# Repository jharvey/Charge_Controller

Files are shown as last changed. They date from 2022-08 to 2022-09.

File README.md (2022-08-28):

# FUGU-ARDUINO-MPPT-HARDWARE-KICAD
An open source Arduino ESP32 MPPT Solar Charge Controller firmware equipped with charging algorithms, WiFi, LCD menus &amp; more!
Stay tuned for the design release and video tutorial.<br>

Orginal Firmware project found here https://github.com/AngeloCasi/FUGU-ARDUINO-MPPT-FIRMWARE<br>
Oringal Hardware project found here https://drive.google.com/drive/folders/1Sd2jWAb-F8NAXlJ6PLdhcnPDQV0alD15?usp=sharing<br>

<div align="center">
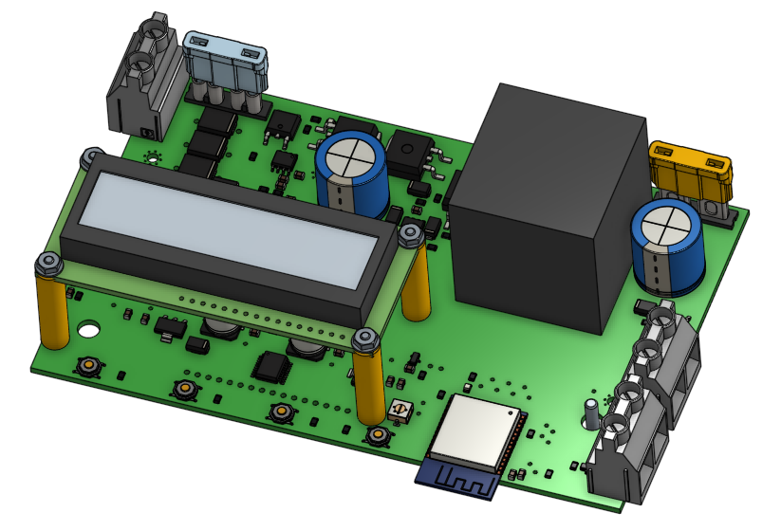
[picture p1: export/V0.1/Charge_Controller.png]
FUGU MPPT Charge Controller

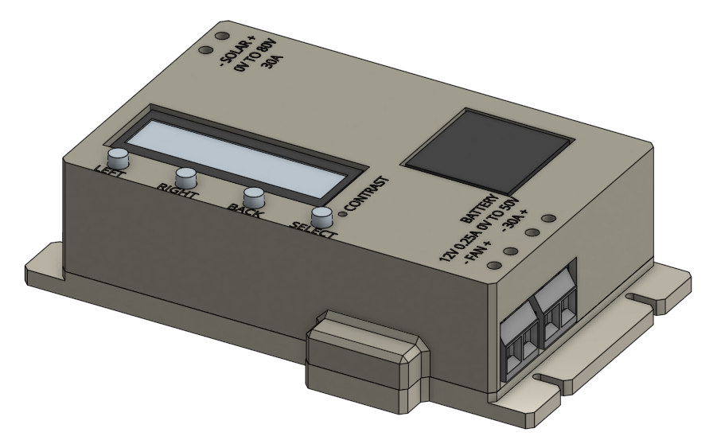
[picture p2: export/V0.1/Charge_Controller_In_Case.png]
FUGU MPPT Charge Controller

<div align="left">
OnShape 3D found here https://cad.onshape.com/documents/5882843f0ee96e62ba8b9faf/w/820f02cb3842ce32ae850702/e/1fe43df2095ddf6be5cc563b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<br>
GPL open-source DIY Charge Controller<br>

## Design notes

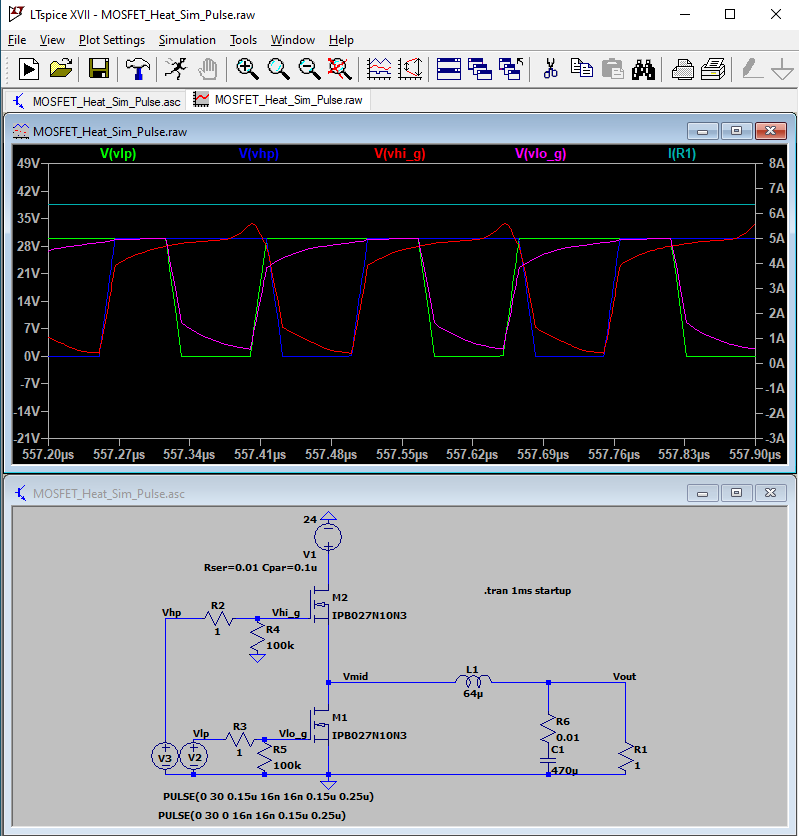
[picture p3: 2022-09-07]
Simulations/MOS_Heat_LTSpice/MOSFET_Heat_Sim_Pulse.png

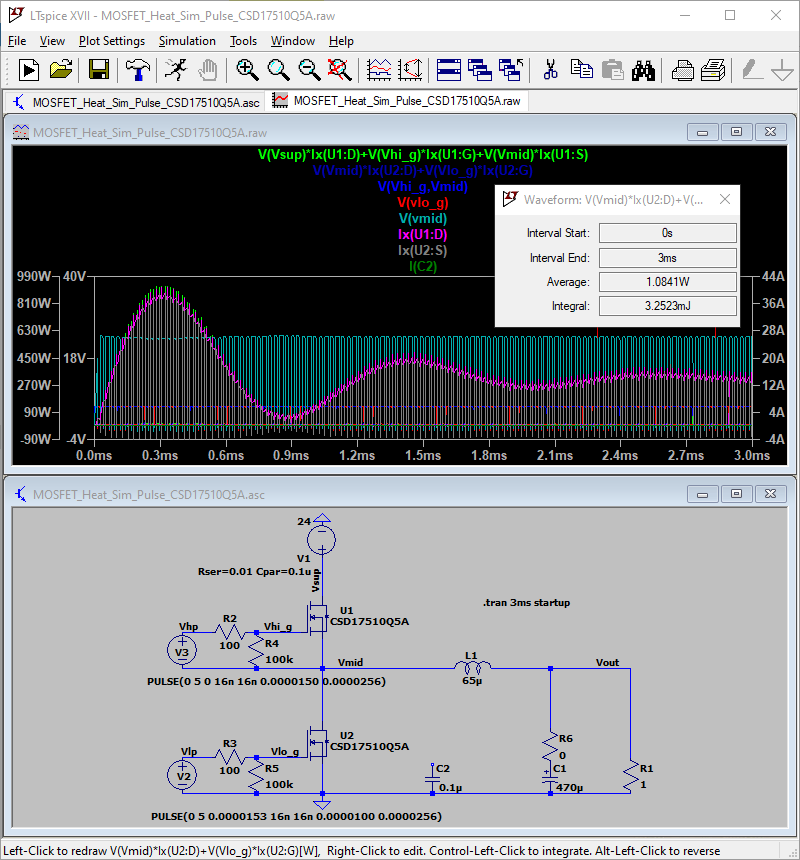
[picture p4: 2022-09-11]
Simulations/MOS_Heat_LTSpice/Low_Side_1.08W_at_12A_Out.png

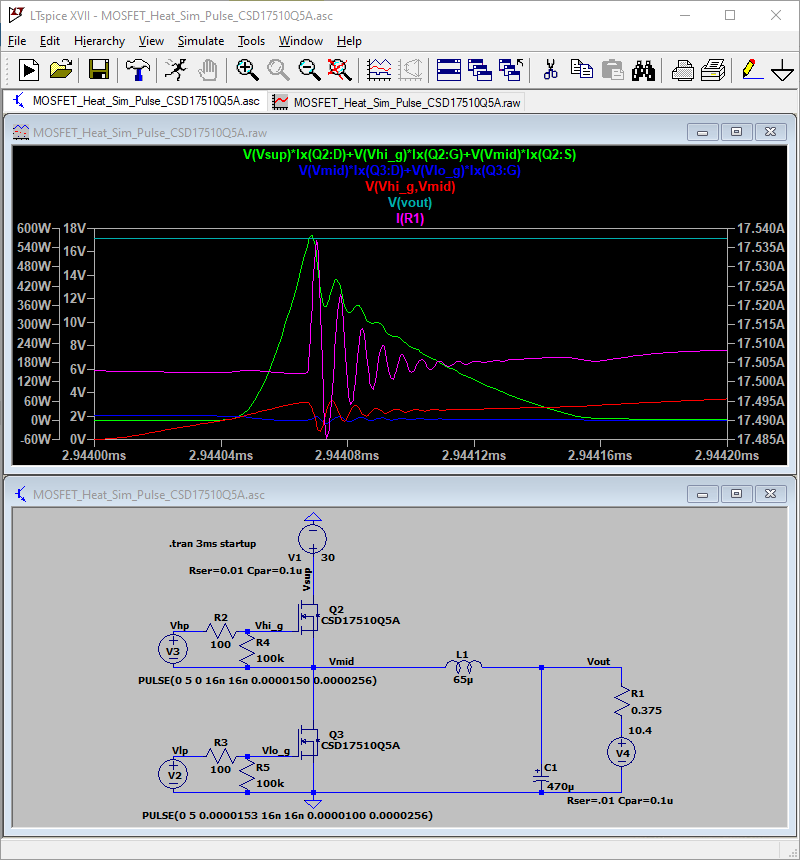
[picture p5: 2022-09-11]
Simulations/MOS_Heat_LTSpice/HeatSim_Q2_Transients_at_30Vin_with_2.944mS_600Wpeak.png

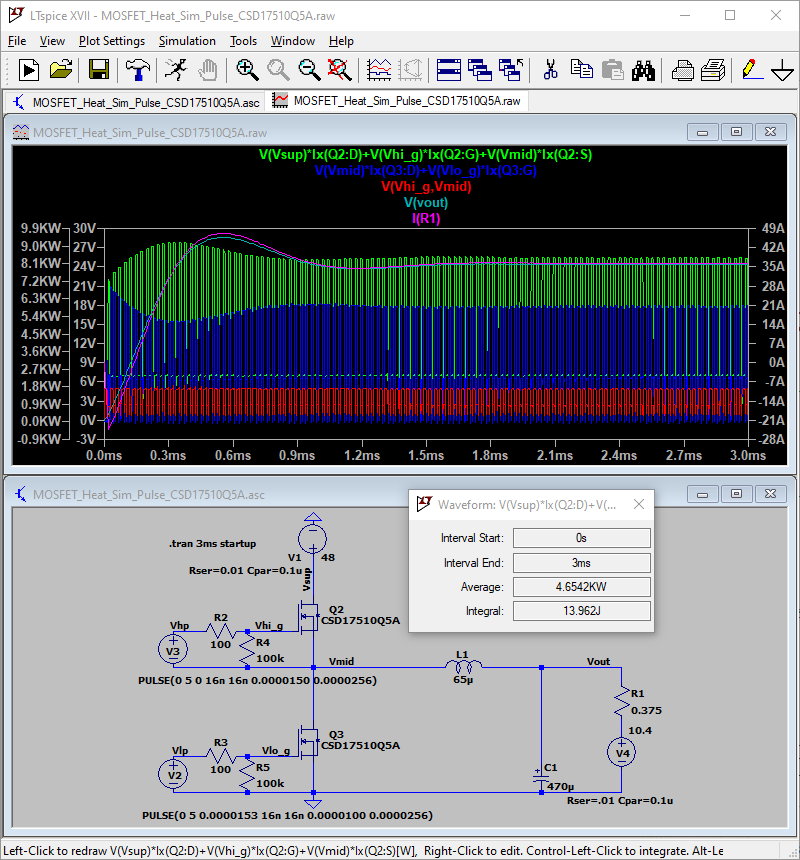
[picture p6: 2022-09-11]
Simulations/MOS_Heat_LTSpice/HeatSim_Q2_4.65kW_at_48Vin_with_36A_26V_Out_Batter_Charger.png

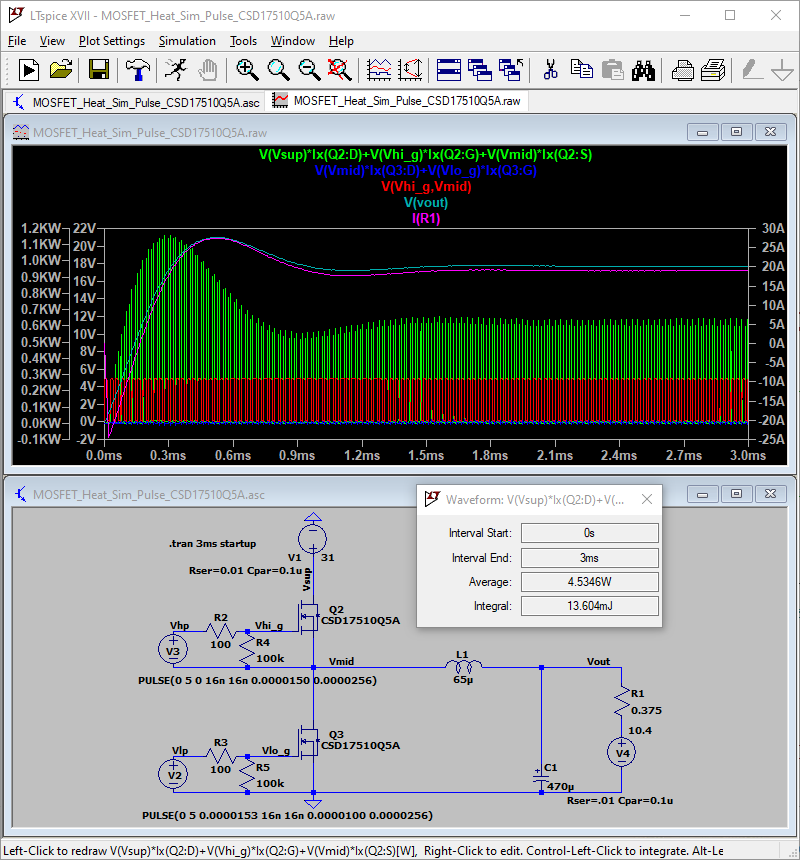
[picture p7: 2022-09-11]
Simulations/MOS_Heat_LTSpice/HeatSim_Q2_4.53W_at_31Vin_with_19A_18V_Out_Batter_Charger.png

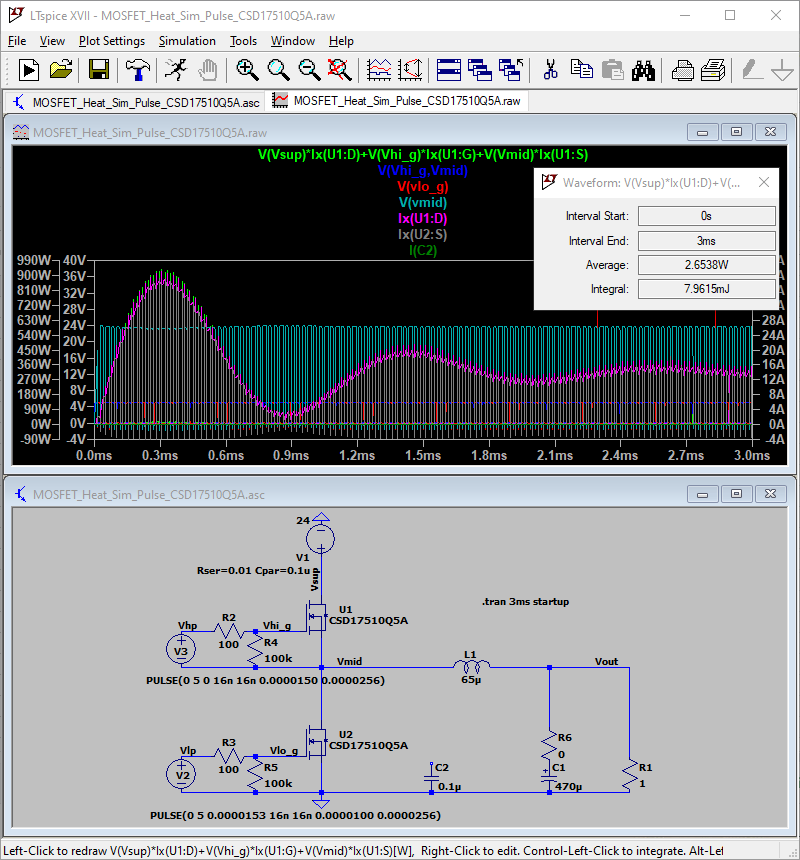
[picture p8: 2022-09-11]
Simulations/MOS_Heat_LTSpice/High_Side_2.65W_at_12A_Out.png

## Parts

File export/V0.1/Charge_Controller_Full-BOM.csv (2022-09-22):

Comment | Designator | Footprint | LCSC
100nf | C1,C3,C4,C11,C12,C13,C20,C23,C25,C26,C27 | Capacitor_SMD:C_0805_2012Metric | C28233
10uf | C10 | Capacitor_SMD:C_0805_2012Metric | C15850
100uf | C14,C16 | Capacitor_SMD:CP_Elec_8x10 | C445063
33nf | C15,C17 | Capacitor_SMD:C_0805_2012Metric | C53175
4.7uf | C18 | Capacitor_THT:CP_Radial_D10.0mm_P5.00mm | C503212
470nf | C19,C28 | Capacitor_SMD:C_0805_2012Metric | C13967
2.2uf | C2,C9 | Capacitor_SMD:C_0805_2012Metric | C49217
4.7uf | C5,C6,C21,C22,C24 | Capacitor_SMD:C_0805_2012Metric | C1779
470uf | C7,C8 | Capacitor_THT:CP_Radial_D16.0mm_P7.50mm | C513392
SS310 | D1,D2,D3,D5,D6,D7 | Diode_SMD:D_SMA | C15874
90V-34A | D11,D12,D13 | Diode_SMD:D_SMC-RM10_Universal_Handsoldering | C2912801
1N4007 | D4,D8 | Diode_SMD:D_SMA | C727081
D_Zener_Small | D9,D10 | Diode_SMD:D_MiniMELF | C8062
LCD | DS1 | LCD:LCD_LCM-S01602DTR_A | C83275
25A | F1,F2 | Symbol:ESD-Logo_6.6x6mm_SilkScreen | C116701
Holder | H1,H2 | Fuse_Holder:Fuse_Blade_C2935871 | C2935871
100x41x8mm Aluminum Heat Sink | HS1 | MountingHole:MountingHole_2.5mm_Pad_Via | NA
SOLAR | J1 | TerminalBlock_MetzConnect:TerminalBlock_MetzConnect_Type703_RT10N02HGLU_1x02_P9.52mm_Horizontal | C92145
Conn_01x01_Female | J2,J3,J4,J5,J6,J7,J10,J11,J12,J13,J14,J15,J16,J17,J18,J19,J20,J21,J22,J23,J24,J25,J26,J27,J28,J29,J30,J31,J32 | TestPoint:TestPoint_Loop_D3.50mm_Drill0.9mm_Beaded | NA
Conn_01x01_Female | J33,J34 | MountingHole:MountingHole_2.5mm_Pad_Via | NA
FAN | J36 | TerminalBlock_MetzConnect:TerminalBlock_MetzConnect_Type703_RT10N02HGLU_1x02_P9.52mm_Horizontal | C92145
I2C_CON | J38 | Connector_PinHeader_2.54mm:PinHeader_1x04_P2.54mm_Vertical | NA
BATT | J8 | TerminalBlock_MetzConnect:TerminalBlock_MetzConnect_Type703_RT10N02HGLU_1x02_P9.52mm_Horizontal | C92145
USB_OTG | J9 | Connector_USB:USB_Micro-AB_Molex_47590-0001 | C136001
64uH | L1 | Inductor_THT:L_Axial_L30.0mm_D8.0mm_P35.56mm_Horizontal_Fastron_77A | NA
7443783533650 | L11 | 7443783533650_inductor:7443783533650 | NA
100uH | L2,L3 | Inductor_SMD:L_Taiyo-Yuden_NR-60xx_HandSoldering | C88132
LED | LED1,LED2 | LED_SMD:LED_0805_2012Metric | C84256
Logo_Open_Hardware_Small | LOGO1 | Symbol:OSHW-Symbol_6.7x6mm_SilkScreen | NA
CSD19505 | Q1,Q2,Q3 | Package_TO_SOT_SMD:TO-263-2 | C485534
Si2306 | Q4,Q9 | Package_TO_SOT_SMD:SOT-23 | C347489
2N3904 | Q5,Q6 | Package_TO_SOT_SMD:SOT-23 | C18536
PMOS-100V-78A | Q7,Q8 | Package_TO_SOT_SMD:TO-252-2 | C216784
200k | R1 | Resistor_SMD:R_0805_2012Metric | C17539
15k | R14,R15,R17,R18 | Resistor_SMD:R_0805_2012Metric | C17475
5.1k | R2 | Resistor_SMD:R_0805_2012Metric | C27834
3.3k | R3 | Resistor_SMD:R_0805_2012Metric | C26010
47k | R32,R33 | Resistor_SMD:R_0805_2012Metric | C17713
10k_-tc | R35 | Connector_PinHeader_2.54mm:PinHeader_1x02_P2.54mm_Vertical | NA
0R | R38,R39 | Resistor_SMD:R_0603_1608Metric | C21189
10k | R4,R6,R7,R12,R13,R20,R21,R22,R23,R24,R25,R26,R27,R28,R29,R30,R31,R36,R37,R43,R46,R47,R48 | Resistor_SMD:R_0805_2012Metric | C17724
330 | R49 | Resistor_SMD:R_0805_2012Metric | C17630
1k | R5,R16,R19,R34,R41,R42 | Resistor_SMD:R_0805_2012Metric | C17513
100k | R8,R11,R40 | Resistor_SMD:R_0805_2012Metric | C149504
100 | R9,R10 | Resistor_SMD:R_0805_2012Metric | C17408
10k | RV1 | Potentiometer_SMD:Potentiometer_Bourns_3314G_Vertical | C780220
RIGHT | SW1 | Button_Switch_SMD:SW_SPST_EVQQ2 | C318884
LEFT | SW2 | Button_Switch_SMD:SW_SPST_EVQQ2 | C318884
BACK | SW3 | Button_Switch_SMD:SW_SPST_EVQQ2 | C318884
SELECT | SW4 | Button_Switch_SMD:SW_SPST_EVQQ2 | C318884
Hall Amp Sense | U1 | Package_SO:SOIC-8_3.9x4.9mm_P1.27mm | C2930869
ADS1015 | U10 | Package_SO:TSSOP-10_3x3mm_P0.5mm | C193969
NUP4202 | U11 | Package_TO_SOT_SMD:SOT-363_SC-70-6 | C89319
PCF8574 | U12 | Package_SO:SSOP-20_5.3x7.2mm_P0.65mm | C57790
B1212 | U2 | Converter_DCDC:Converter_DCDC_muRata_CRE1xxxxxxSC_THT | C5127060
AMS1117-5.0 | U3 | Package_TO_SOT_SMD:SOT-223-3_TabPin2 | C6187
AMS1117-3.3 | U4 | Package_TO_SOT_SMD:SOT-223-3_TabPin2 | C6186
XL7005A | U5,U6 | Package_SO:SOIC-8_3.9x4.9mm_P1.27mm | C50848
IR2104 | U7 | Package_SO:SOIC-8_3.9x4.9mm_P1.27mm | C2960
ESP32-WROOM-32 | U8 | RF_Module:ESP32-WROOM-32 | C701343
CH340C | U9 | Package_SO:STC_SOP-16_3.9x9.9mm_P1.27mm | C84681
Comment | na | na | McMaster
Passivated 18-8 Stainless Steel Phillips Flat Head Screw 82 Degree Countersink 2-56 Thread 1-1/2" Long |  |  | 91771A267
Passivated 18-8 Stainless Steel Phillips Flat Head Screw 82 Degree Countersink 2-56 Thread 1-1/2" Long |  |  | 91771A267
Passivated 18-8 Stainless Steel Phillips Flat Head Screw 82 Degree Countersink 2-56 Thread 1-1/2" Long |  |  | 91771A267
Passivated 18-8 Stainless Steel Phillips Flat Head Screw 82 Degree Countersink 2-56 Thread 1-1/2" Long |  |  | 91771A267
316 Stainless Steel Washer for Number 2 Screw Size 0.094" ID 0.25" OD |  |  | 90107A003
316 Stainless Steel Washer for Number 2 Screw Size 0.094" ID 0.25" OD |  |  | 90107A003
316 Stainless Steel Washer for Number 2 Screw Size 0.094" ID 0.25" OD |  |  | 90107A003
316 Stainless Steel Washer for Number 2 Screw Size 0.094" ID 0.25" OD |  |  | 90107A003
18-8 Stainless Steel Nylon-Insert Locknut 2-56 Thread Size |  |  | 91831A002
18-8 Stainless Steel Nylon-Insert Locknut 2-56 Thread Size |  |  | 91831A002
18-8 Stainless Steel Nylon-Insert Locknut 2-56 Thread Size |  |  | 91831A002
18-8 Stainless Steel Nylon-Insert Locknut 2-56 Thread Size |  |  | 91831A002
Off-White Nylon Unthreaded Spacer 1/4" OD 1" Long for Number 2 Screw Size |  |  | 94639A198
Off-White Nylon Unthreaded Spacer 1/4" OD 1" Long for Number 2 Screw Size |  |  | 94639A198
Off-White Nylon Unthreaded Spacer 1/4" OD 1" Long for Number 2 Screw Size |  |  | 94639A198
Off-White Nylon Unthreaded Spacer 1/4" OD 1" Long for Number 2 Screw Size |  |  | 94639A198
Zinc-Plated Steel Phillips Flat Head Screws 82 Degree Countersink Angle 4-40 Thread Size 5/8" Long |  |  | 90273A112
Zinc-Plated Steel Phillips Flat Head Screws 82 Degree Countersink Angle 4-40 Thread Size 5/8" Long |  |  | 90273A112
3D printed base enclosure
3D printed top enclosure
3D printed push button extenders

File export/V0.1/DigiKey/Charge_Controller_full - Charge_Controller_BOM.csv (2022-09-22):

Reference | Quantity | Value | Footprint | Datasheet | Field4 | LCSC | Digikey
DS1 | 1 | LCD | LCD:LCD_LCM-S01602DTR_A |  |  | NA | 3387-ACM1602K-NLW-BBW-ND
C18 | 1 | 4.7uf | Capacitor_THT:CP_Radial_D10.0mm_P5.00mm |  | 100v | NA | 399-ESH107M100AH4AA-ND
R35 | 1 | 10k_-tc | Connector_PinHeader_2.54mm:PinHeader_1x02_P2.54mm_Vertical |  |  | NA | BC2380-ND
L1 | 1 | 64uH | Inductor_THT:L_Axial_L30.0mm_D8.0mm_P35.56mm_Horizontal_Fastron_77A |  | 36A optional hand wound inductor | NA | 495-5076-ND
L11 | 1 | inductor:7443783533650 | 7443783533650_inductor:7443783533650 |  | 17.2A | 732-13654-ND

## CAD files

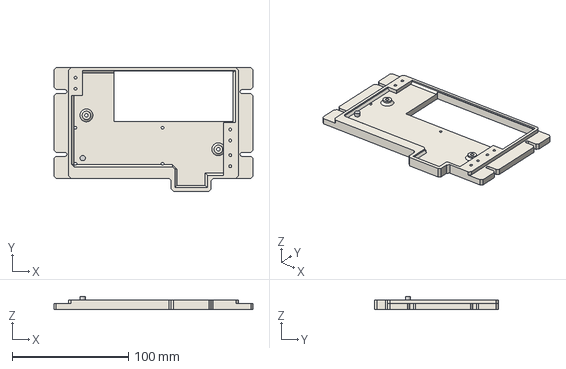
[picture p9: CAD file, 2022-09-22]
export/V0.1/case_bottom.step
171.4 x 106.5 x 11.4 mm

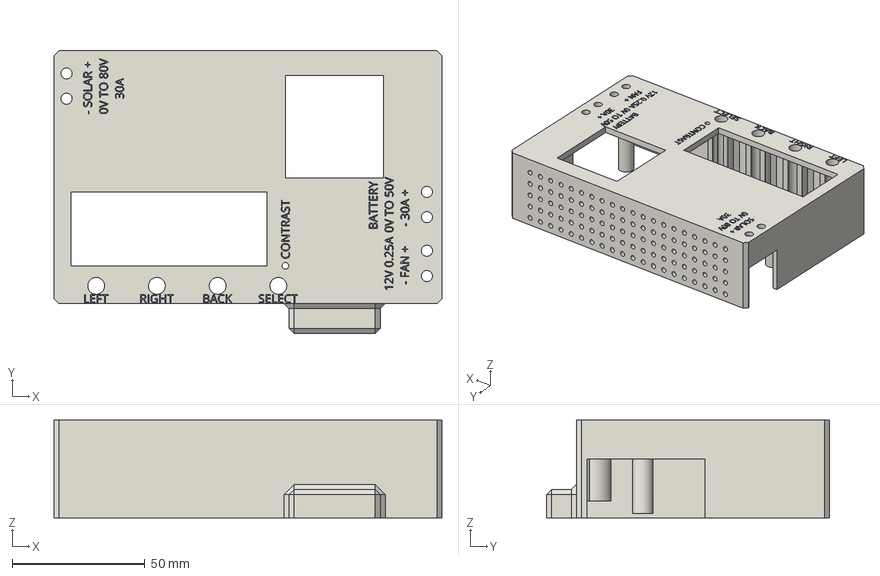
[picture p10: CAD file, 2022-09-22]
export/V0.1/case_top.step
146.0 x 106.5 x 36.8 mm

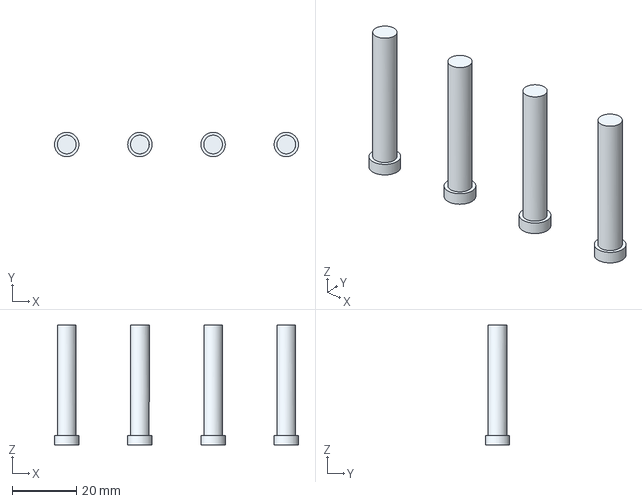
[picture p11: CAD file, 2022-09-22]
export/V0.1/Buttons.step
76.2 x 7.62 x 37.4 mm

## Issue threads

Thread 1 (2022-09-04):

Design review

krzysztof9nowak, 2022-09-04:
Hi, I am no electronics guru, but here are my suggestions.
## Schematic:
- Move C7 as shown on the screenshot. When buck converter operates, the current flowing between C7 and Q2 is a square wave. If this square wave current passes through ACS712 it introduces unnecessary noise to input current readings and increases losses on Q1 (according to P=I^2*R).
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
- Input fuse F1 might be unnecessary. MPPT current of a solar panel is about 90% of short circuit current, so it's impossible to select a fuse, which would fail on short circuit. However, I would consider adding some over-voltage protection in form of either Zener diodes or varistors, which could protect from voltage spikes induced by lightning strikes.
- Isolated converter U2 can be replaced by a simple bootstrap circuit made from two transistors.
- What core are you using for L1? 6 turns seems to be low for 64uH.
## Layout:
- The current loops of the converter seem excessively large. Have a look at [this guide](https://fscdn.rohm.com/en/products/databook/applinote/ic/power/switching_regulator/converter_pcb_layout_appli-e.pdf)
- Transistor Q3 will make poor contact with the heatsink and limit it's airflow.
- The radiator seems a bit small, do you have any thermal specs or calculations for it?

jharvey, 2022-09-05:
Hmmm, fuses are to prevent fire. Typically located at the source so you remove the source of energy. I typically don't size fuse to protect the devices, I typically size to protect the wires or things that can catch fire. I also don't like fuses, it's hard to properly size them for I2T issues. In this case the pulsing will cause high amps for short periods of time, so I2T issues are elevated. I tend to think the fuse should be closer to the panel, if it should be there at all. Some times I use a fuse as it's easier to repair then a burnt copper trace.

L1 includes Digikey part number 495-5076-ND. The schematic properties includes part numbers for either JLC or Digikey. I was planning for 12AWG wire, and I used this prediction tool to predict 6 wraps. https://coil32.net/online-calculators/ferrite-torroid-calculator.html I think 10AWG might also fit, but insulation thickness is likely a concern. Of course if you need more windings, then it may not work either.

I recently found the below. Any thoughts about cramming 50A through a SO8 package?
https://jlcpcb.com/partdetail/MagnTek-MT9223CT50BR5/C2930869

I'm concerned about I2R on the traces. I included J33 and J34 as an option to add a copper wire to help keep the current off the PCB layers.

I was not able to make meaningful predictions of heat generated by Q1, Q2 or Q3. Rds generated watts was not helpful, the real heat will be the transient conditions. 2.6mOhm * 35A^2 = 3W.  I don't much about what the losses will be during the switching. How many watts do we think we need to get out of these? Q3 also wants more electrical insulation from the heatsink. Which isn't going to help the situation. I also should pick a fan and some how include that in the 3D printed case. If I had some kind of prediction of the watts, or some kind of empirical data to work from, then I could make a better thermal prediction.

Q1 and Q2 secretly conduct a bunch of the electrical energy via the screw on the tab. I expect the copper layers are not large enough, but copper with tabs bolted together should be good. Looks like the C7 change will either be a huge layout change or I might just bolt the cap to heat sink. That's going to be a bit of work to change.

I hear you about the current loops. I'm expecting this to be around 20kHz. Is that a proper frequency to be expecting? I really don't know the low core frequency to be considering.

I'm USA eastern standard time. If a phone call helps perhaps we can phone.

jharvey, 2022-09-05:
This is a good layout reference https://www.maximintegrated.com/en/design/technical-documents/tutorials/5/5450.html specifically the simulations showing you that at about 1KHz the ground plane currents start to follow the matching trace.

jharvey, 2022-09-07:
I've tried several simulations to predict the heat generated by Q1, Q2, and Q3. So far this is the best I've managed. It uses a similar but different MOSFET and actually simulates with out crashing. I see PSPICE for TI offers the actual MOSFET being used. However it appears the spice model has a typo in the .ENDS part of the SPICE model, as it errors out and does not compile. In the LTSpice I'm learning how to create an equation to multiple the instantaneous V * A for the MOSFET, then I can plot that to see the instantaneous watts.

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

jharvey, 2022-09-08:
Small progress, looks like I'll have to use the pulse file power supply, which allows precision timing of the pulses. Currently this model shows KA and KW of energy dissipated by the MOSFET's. So Looks like I'll have to create a spreadsheet which will then create the timing pulses. This will allow precision timing of dead times. Anyhow incremental progress.
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

jharvey, 2022-09-09:
I wonder if I can get LTSpice to integrate so I can make a prediction of the heat generated by the MOSFET. In the below simulation, with only the high side drive, I see these large but short spikes of heat. Like 300W during the transition stage, and basically 0W any other time. I really need to know the area under the curve to know what kind of energy the heat sink needs to deal with.

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

jharvey, 2022-09-09:
In LTSpice after you run the simulation, you can add probes. If you hit the alt button, then select a component, it will graph the instantaneous watts for that component. Then if you hit crtl and click the text of that trace, it will integrate what ever is in the graph. I did this for just the high side MOSFET, of similar Rds while it was running at about 19 amps. For 10mS it averaged at 15W.

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

jharvey, 2022-09-09:
I've got the PWL file created and now the simulation seems a bit more sane. How does this look? I can now control the delays between the high and low sides. This zoomed in view shows the transient spikes in amps and watts.

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

For the high side I get a watts prediction in the low mW

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

For the low side I get a watts prediction around 1W.
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

Do these predictions seem sane? I feel like the original design had a fan for a reason. With this particular pulse train, when the output is 5V @ 4A. Under those conditions I guess the heat sinks handling 1W is not that crazy. I guess I need to figure out how to get the pulse train to produce more volts and more amps.

jharvey, 2022-09-11:
@krzysztof9nowak
> * The radiator seems a bit small, do you have any thermal specs or calculations for it?

The simulation has finally produced some results. I obtained the SPICE for the CSD17510Q5A from PSPICE for TI, by exporting the file, then importing it into LTSpice. This seems to be producing a fairly decent watts generated prediction.

It's not perfect, I couldn't get the simulation to always work, for some reason it would lock up if V1 went above about 31V, then it would start working again if it was at around 48V. I'm assuming that's some kind of limit embedded in the SPICE file. However if it was at around 48V, the MOSFET's claimed to dissipate KW instead of W, As well I had to be cautious when V4 was around 15V, as it would commonly back flow L1. With these limitations in mind, and with some very finely tuned on and off times, I think I have a fairly good prediction of the watts that Q2 and Q3 generate. I believe Q1 is just on or off, so the RDS predictions for that should be fine. So we'll call that 35A^2 * 3mOhm = 3.7W.

In the below, Q2 claims 27A output and less then 5W.
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

Then Q3 in this same simulation is 2W.
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

I see many items which need to be very closely monitored. For example the V2 the parameter which is 0.0000153 needs to be between about 0.0000151 to 0.0000155. If it's outside that range, then the MOSFET dissipates KW instead of W.

For now I'll plan for Q2 = 5W and Q3 = 2W. So I'll call it about 10W total.

The [MOSFET](https://www.ti.com/lit/ds/symlink/csd19505kcs.pdf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) max junction temp is 175C, and it has 0.5C/W from junction to heatsink.

The [HeatSink](https://www.assmann-wsw.com/uploads/datasheets/ASS_0498_HS.pdf) has a about 6C/W rise with a small fan, but could be 2.5C/W with a more powerful fan.

So rise is about 10W * (0.5C/W + 6C/W) = 65C rise. So the ambient could be as high as 110C before it hits the limit of the MOSFET junction. The ambient is more likely to be below 40C, so the rise could get up to 105C. I tend to start getting concerned above 85C, as FR4 often starts to fatigue around 85C. As well a 3D printed case is probably only good to around 45C to 55C.

I think the heatsink in the BOM should be OK, but I would prefer if it was larger. I'd prefer it if worked better with out a fan.

jharvey, 2022-09-12:
> * What core are you using for L1? 6 turns seems to be low for 64uH.

During my simulations efforts I found the below. It's only 17.2A, but it's a purchasable option, and I don't have to design it's internals, they simply tell me it can handle 17.2A so I assume the saturation is OK.
https://octopart.com/search?q=7443783533650

jharvey, 2022-09-22:
@krzysztof9nowak

I have published a revised design. Thank you for your feedback. If you feel so inclined a second review would be great. Here are some key notes of interest.
-- L11 is the intended inductor, or you can optionally wind your own L1. L11 has a datasheet with published temperature rise, I'm a bit concerned about this expected rise in temp.
-- 100x41x8mm Aluminum Heat Sink seem reasonably priced on ebay. HS1 could have a screw to keep a tight fit to this heat sink. The heat sink will need clearance for thru hold components. These clearance areas could be done with a hand drill.
-- I left U2, as I don't see how to make this work with a bootstrap circuit.
-- in higher power designs, J33 and J34 could bolt to a heatsink, which also helps keep the currents off the GND plane.

krzysztof9nowak, 2022-09-22:
Hi, sorry for lack of response, I was busy with other work. I see you really played around with the simulations. As you observed the dead-time is critical, but thankfully that's handled by the IR2104 driver. Also thanks for the nice LTSpice tricks.
- The L1 has good saturation current, I'm not sure. I don't really understand what the temperature rise is describing in the datasheet. The book on understanding and designing inductors I can recommend is: "Inductors and Transformers for Power Electronics" by Vencislav Cekov Valchev and Alex Van den Bossche (2005, CRC Press). You should be able to find it online.
- The 10W estimate seems reasonable. However I have no idea how well the FR4 will transfer heat from SMD transistors to the other side. In have my MOSFETs mounted like this:
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
(excuse the misaligned holes, I only had a hand drill on hand, when I assembled it)
In the worst case you will mount it to a bigger heatsink.
- You are right, it's better to leave it with U2. I had some ideas but they aren't very reliable.

I think everything looks okay and you are good to go.

jbaltes, 2023-07-02:
L1 part saturation: TDK  495-5076 allows 500mT at 25dgrC vor 410 at 100dgrC (Material N27): https://www.tdk-electronics.tdk.com/download/528850/3a7f957d754f899aec42cd946598c5c4/pdf-n27.pdf
B=N*I*AL/Ae=6*10A*1940nH/33.63mm^2=3461mT - so I think saturation is violated with this core even at only 10 A

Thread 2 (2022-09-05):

Change location of C7 to other side of current sensor

jharvey, 2022-09-05:
@krzysztof9nowak commented
> * Move C7 as shown on the screenshot. When buck converter operates, the current flowing between C7 and Q2 is a square wave. If this square wave current passes through ACS712 it introduces unnecessary noise to input current readings and increases losses on Q1 (according to P=I^2*R).
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

C7 has been moved. As well C8 has been changed from Axial to Radial cap.

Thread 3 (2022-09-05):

Add input surge suppression

jharvey, 2022-09-05:
@krzysztof9nowak commented
>- Input fuse F1 might be unnecessary. MPPT current of a solar panel is about 90% of short circuit current, so it's impossible to select a fuse, which would fail on short circuit. However, I would consider adding some over-voltage protection in form of either Zener diodes or varistors, which could protect from voltage spikes induced by lightning strikes.

What do you think about this TVS? https://jlcpcb.com/partdetail/Brightking_Elec_taiwan-50SMDJ120CA/C729864 I see it's 26A peak amps. I'm not finding much for a better option at JLCPCB. I'd like more like 50A peak, so it has a chance of blowing the fuse if there is a surge event.

jharvey, 2022-09-05:
I did this with the below TVS, it's 34A at 90V.
https://jlcpcb.com/partdetail/Yint-50SMDJ90CA/C2912801

I used multiple TVS diodes in hopes that the amps will blow the fuse, as one fuse is not enough to pop a 35A fuse. I used a SMC footprint which also include thru holes, which should allow for other options if they are found. Seems like most options are SMC or thru hole. I also re-arranged the circuit a bit, so that the fuse is first, then surge protection then the rest of the circuit.

krzysztof9nowak, 2022-09-06:
Multiple TVS looks good.

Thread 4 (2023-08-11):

Wrong resistor values in 3.3v regulator

joostn, 2023-08-11:
Hi, thanks for making this available!

Just wanted to point out that the resistor values for the 3.3v regulator (R17/18/19) are wrong, this will fry your ESP32. In Angelo's original design they are 33k/33k/10k.

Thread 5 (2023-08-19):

TXD/RXD connected wrong

joostn, 2023-08-19:
CH340 TXD should be connected to ESP RXD and vice versa

joostn, 2023-08-19:
Also, the NTC temperature sensor is connected wrong: it should be connected to V3.3, creating a voltage divider with the 10k resistor

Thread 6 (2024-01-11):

Status of this project?

P0rkR0ll, 2024-01-11:
Did you get this PCB made? Do you need any more eyes lookin over it?

I'm trying to get one of these installed in my truck :)

jharvey, 2024-01-11:
@P0rkR0ll I have not made this yet :( I've become distracted with other projects. What's your project? Perhaps I can get this to a point were it can be prototyped. I've got 2 kids 13 and 15 yr old. My time to do the physical prototype is limited, but I can often do design stuff after the family has gone to sleep. What is your level of electrical knowledge? I'd be happy for an extra set of eyes.

P0rkR0ll, 2024-01-11:
Haha, i know how that goes, I am in a VERY similar boat. I have lots of experience laying out power supply PCB's and doing all heat calcs, and decades of mechanical CAD experience. I'm really good at following reference designs haha. I'm interested in this project because it looks like a lot of the real hard stuff with sch and firmware control logic is mostly done, and I wanna take it and wrap it up in a cool package. I've been looking for an excuse to make a project where the PCB is the enclosure, with capacitive touch buttons, and something better than a 4x20 display from the radio shack kit i had as a kid. OLED screens are cheap and way cooler. I have a buddy with loads of exp designing crazy power supplies, and he said the original circuit and code was good, he even bought some PCBs but never put them together. I want this because it is kinda a swiss army knife of a DC-DC converter, which would be really handy for some of my other projects. So I can ask my bud to look over what you got, compare it to the original, and then I can work some magic on it. I might try to figure out how to add 20w USBC-PD charger to the original design, to make it more handy

jharvey, 2024-01-11:
My longer term goal with this project was to put an entire inverter setup on the backside of a solar panel, including a battery, pure sine wave 120VAC and potentially a cooling fan or hot water pipe. See my efforts and slow progress here. https://github.com/jharvey/Solar_Kit

My vision for that project is for the solar panels to sit in the garage, then when power goes, I roll out one or multiple panels with 2 wheels attached. The panels would also have a handle, which doubles as a prop rod. So I roll it into the yard, kick out a built in prop rod, and plug in devices. Excess energy is stored in a lead acid battery. I was looking at lead acid as it's heavy, which is handy and helps prevent the panel from blowing over or something like that. I was also planning that if you plug in multiple of these panels into each other, they identify each other and sync. So more panels means more power. The solar kit is very much still a work in progress. It's also an off shoot of this project.

I like the idea of using the PCB as a part of the enclosure, or perhaps even use it as the entire enclosure. I also like OLED's. This used the older school LCD as I think the code is already written that way. I personally would prefer an e-ink display. The refresh rates are not critical and I see no need to burn extra energy. I know the LCD is small energy, but if I'm using it when power is out, small energy is still a concern.

P0rkR0ll, 2024-01-11:
RE OLED screen- I like them because they are like $1.50. Its not a problem to put another free capactitive touch button down to wake up display and have it time out after 30s, this is code I can actually write myself

jharvey, 2024-01-12:
It seems you are driven by low cost. I'm typically driven by a certain level of quality or set of features then low cost after that. I tend to like push buttons which require some mechanical strength to activate them. Cap sense can get false triggers and if you were not present to observer, then you don't know if a cat brushed up against it, or if it was some stray RF noise. In most situations I tend to prefer the extra couple pennies to avoid these types of electrical issues.

You mention you're good at following reference designs. I'm guessing you are Asian. I'm also guessing your interested in cost because you are looking to produce an item for sale. If that is correct I want to note that I am OK with this. I would likely be a customer if they came up for sale. I've helped other projects like rusEFI do that. He sells PCB designs I've designed. I'm happy that he is been able to do great things with my contribution.

I've got a 3 day weekend starting. I might start a branch with an OLED. I agree those are nicer and I expect they will be around forever. I'm not sure how you get free cap sense. Are there pins on the ESP32 which I should avoid if possible? If I know the potential use of them, I can avoid those pins to prevent future issues.

P0rkR0ll, 2024-01-12:
Haha, i'm actually an old white dude living in USA that likes pork roll egg and cheese sandwiches. I do have a lot of experience bringing dozens of products to store shelves and working in and with China. I wasn't actually looking to make a product out of this (at least not one that makes me money), I really just want a swiss army knife DC-DC converter in a nice package, because it would be super handy, and an excuse to sink way too much time into cool enclosure design

RE cap touch: I'm not 100% sold on this, I just think it looks cool, and cheaper\easier to make a drip\splash resistant enclosure design. I've done it with Atmel MCU's in the past, I didn't think ahead far enough to remember this was ESP based haha. I might consider using a dedicated touch controller, which is better for handing issues you describe anyways. Code also helps, things like requiring long touches to 'wake up' the touch pad to avoid accidental touch, that kind of thing. Basically the same thing you'd do with buttons

If I were to add cost to this PCB, my pref would be towards overrating heatsink to eliminate need for fan, water resistant wire connections, external ESP antenna. E-ink is super cool, but super expensive, I haven't found many projects to justify the cost of them. The board can be made so user can pick whatever display they want and solder it in. Bringing it back to OLED display, the question i'm wondering is, do I design it to use an OTS aliexpress module that has .1" header, or get the raw display and solder the ribbon cable down?

The big black square in your pics, is that the 12v DC-DC isolation converter? Can we use smaller ones of those? I've used ones like this and laid them on their backs so they are not tall off the PCB: https://www.digikey.com/en/products/detail/mornsun-america-llc/B1212S-1WR3/13968708

jharvey, 2024-01-14:
Black box is a transformer. The original design was a hand wound a transformer. I designed with a purchased one from digikey.

I'm also an old white born and breed merica. Or al least my teenage kids call me old :)

Do you have a time line for when you want your swiss army knife? What increments are needed before ordering the first proto?

jharvey, 2024-01-14:
I kind of miss these gh comments. Perhaps migrate to email?

Mail@jaredharvey.com

jharvey, 2024-01-18:
@P0rkR0ll Do you have a time line for when you want to build this? Would you be interested in spinning this board? Would you like me to make changes or do you want to fork and clone your own repo to make the changes?

P0rkR0ll, 2024-01-18:
hey bud, i'm not on here that much either. I have a bunch of family visiting too so i'm a little tied up with that. TBH, I have a freelancer dude that i've used many times, and I might just pay him to lay out the PCB. I have a lot of comments to your responses written up already, i'll post it when I get a min. And perhaps, keep the convo on git so everyone else can see our thought process

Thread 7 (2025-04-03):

Is there an error on the ACS712?

noeldum, 2025-04-03:
See the diagram for the ACS712.

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

It looks like the pin to be connected to the 2.2uf capacitor is FILTER and not VOUT.

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

The datasheet also suggest this.

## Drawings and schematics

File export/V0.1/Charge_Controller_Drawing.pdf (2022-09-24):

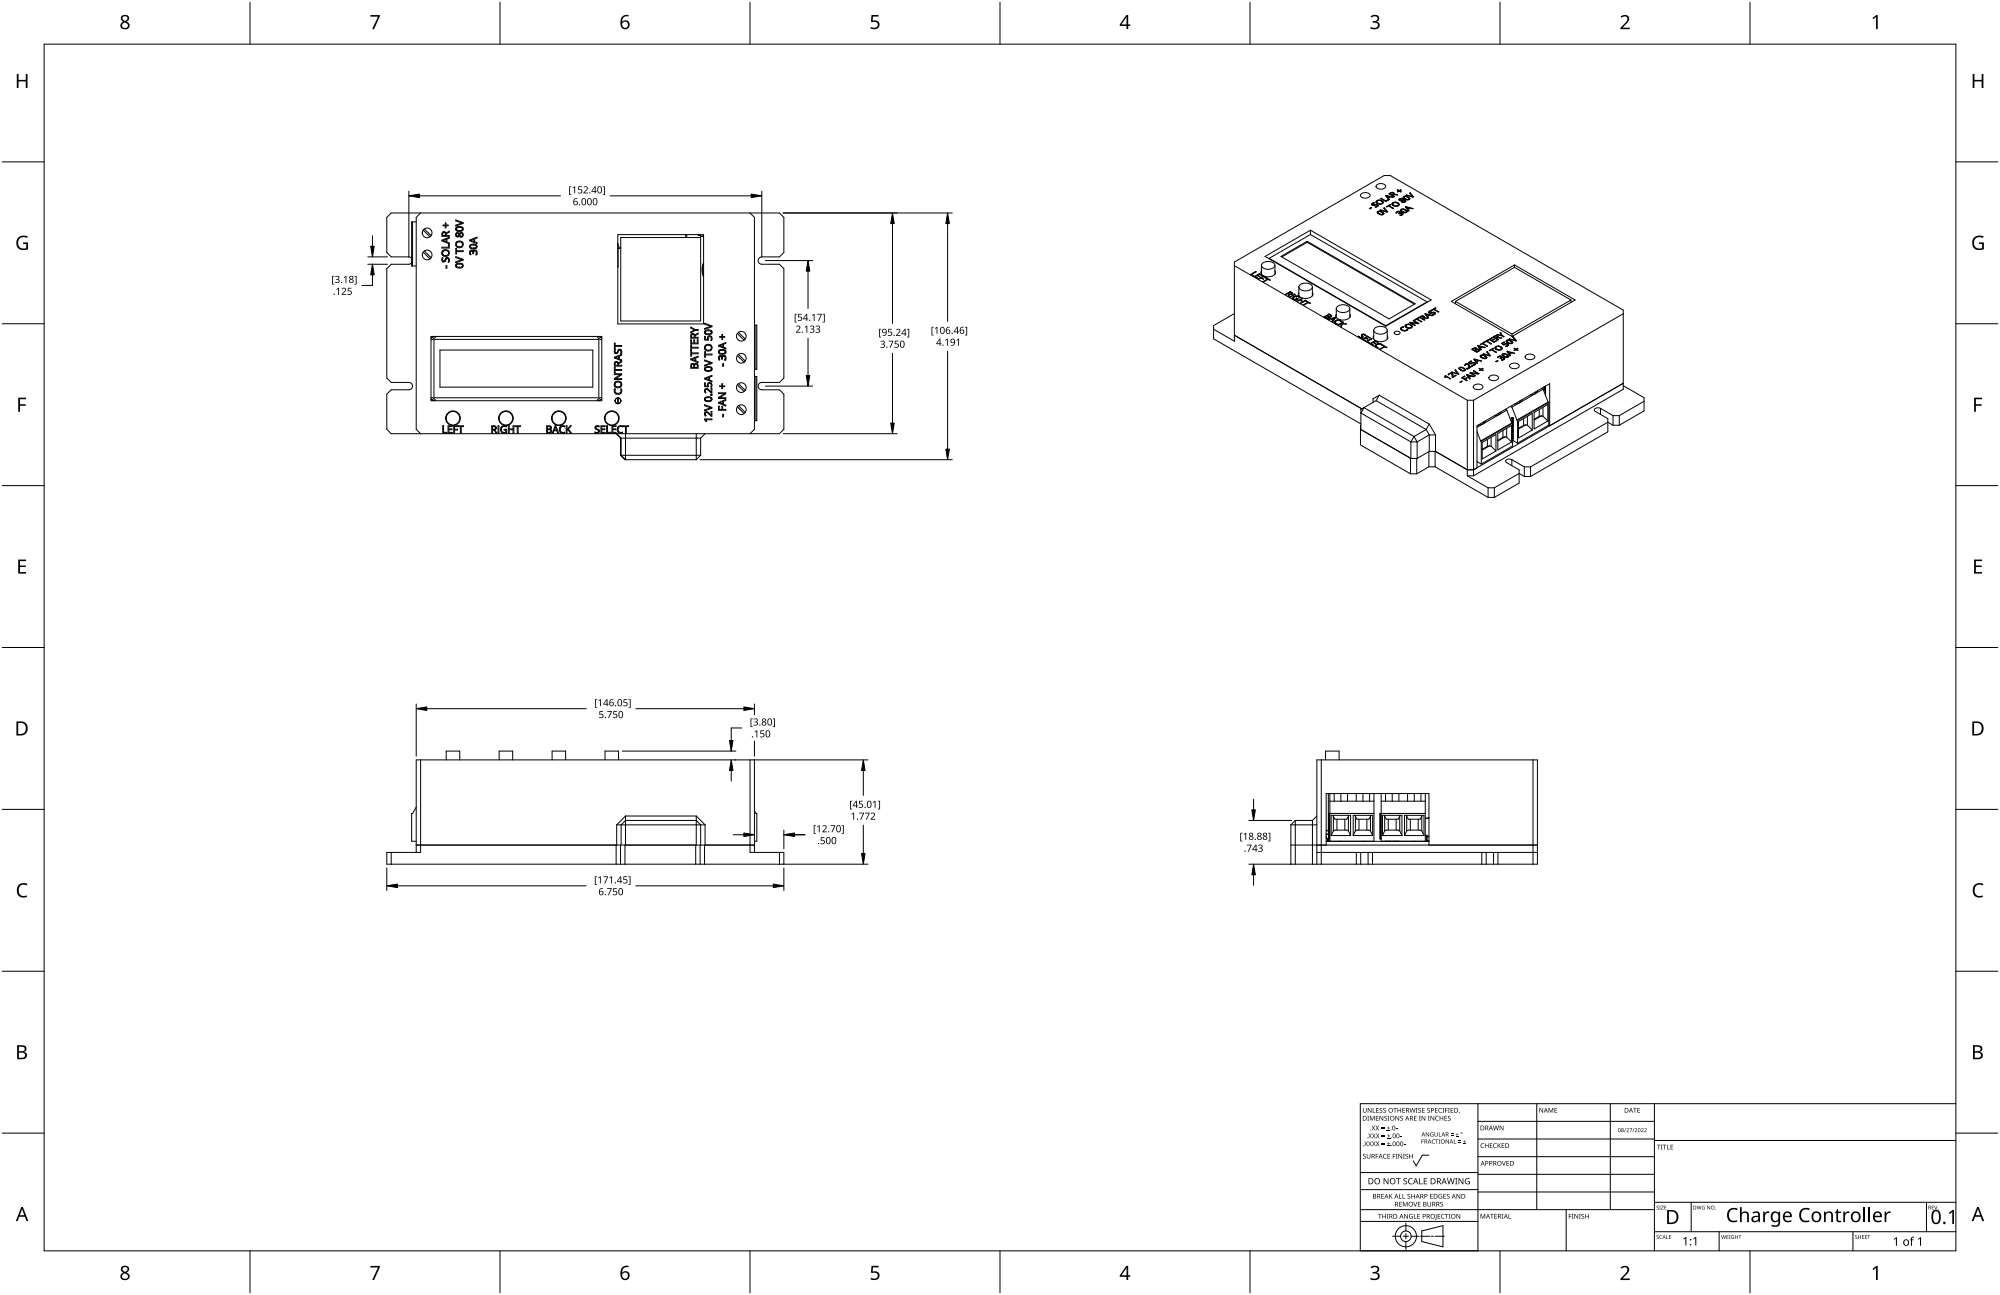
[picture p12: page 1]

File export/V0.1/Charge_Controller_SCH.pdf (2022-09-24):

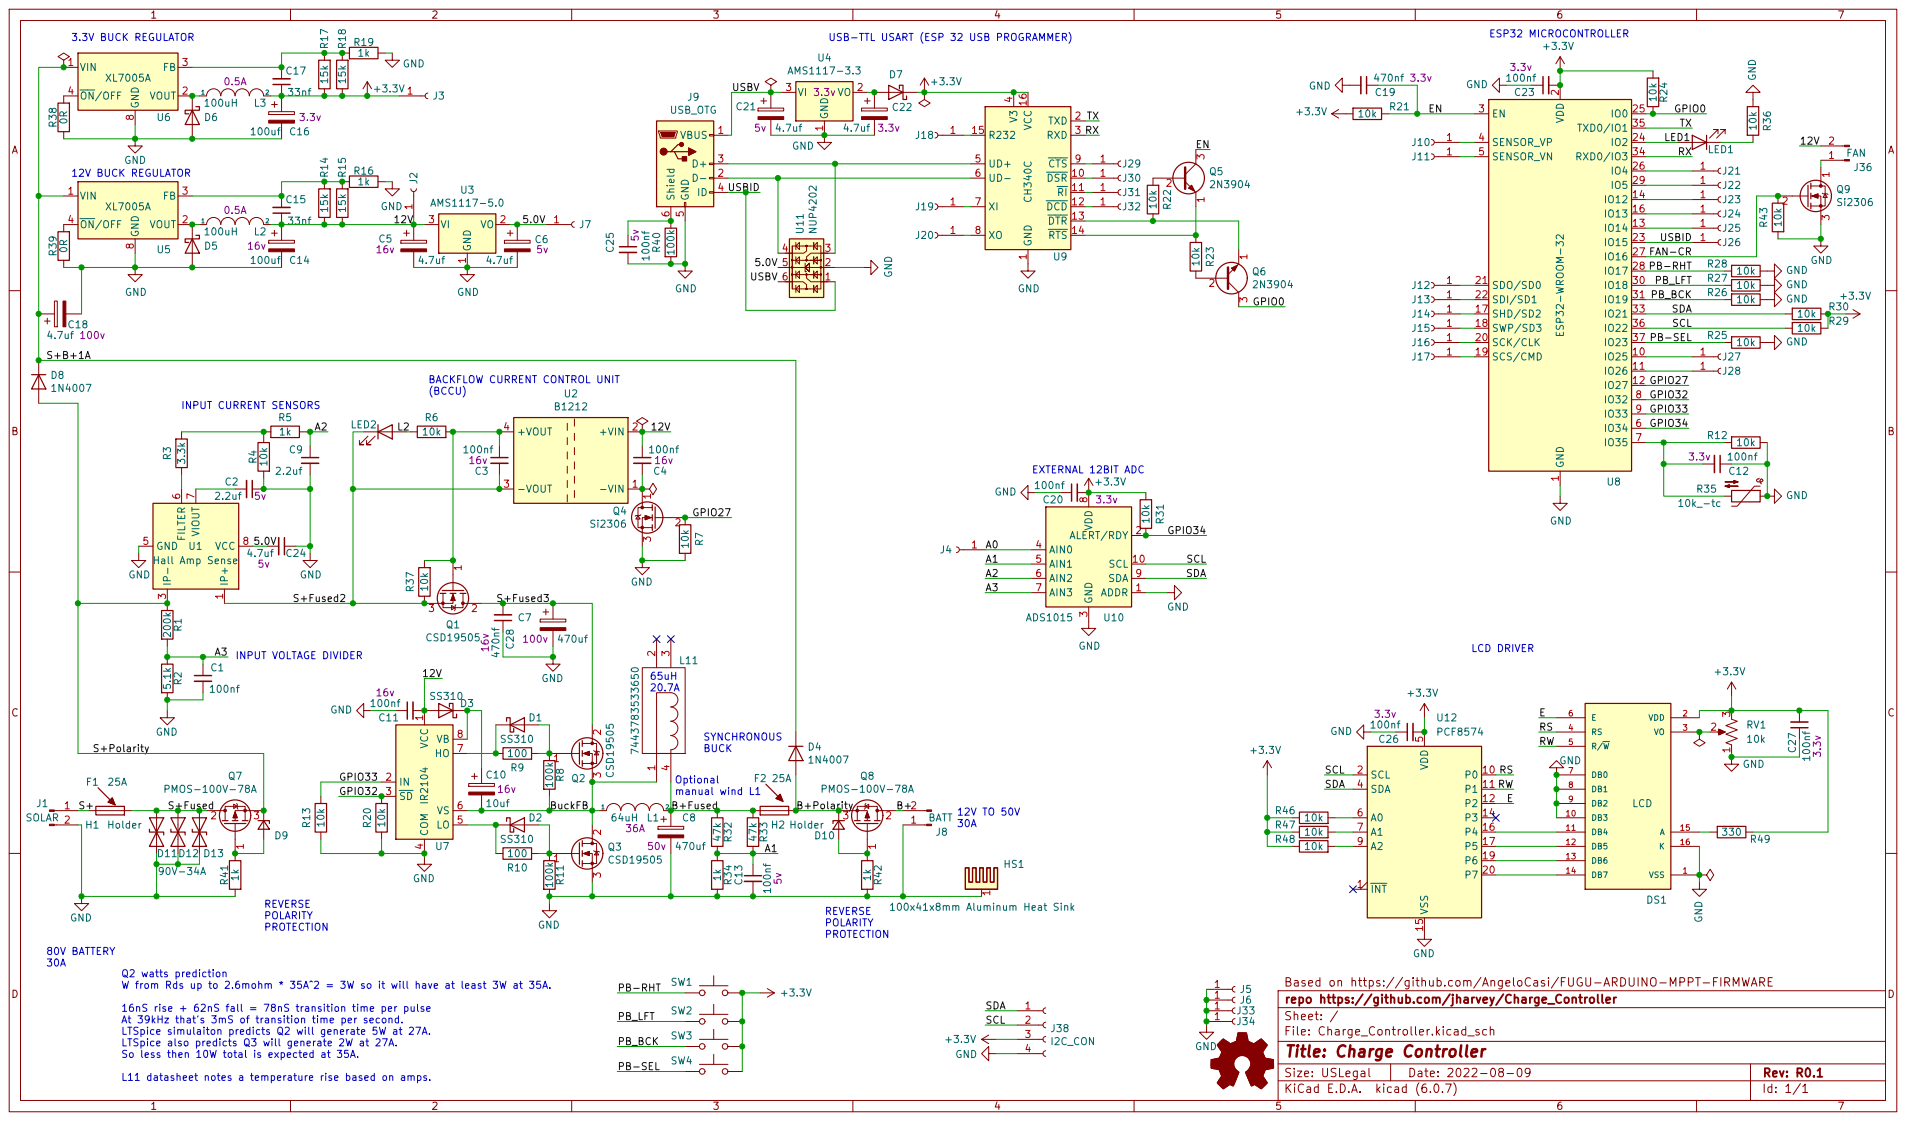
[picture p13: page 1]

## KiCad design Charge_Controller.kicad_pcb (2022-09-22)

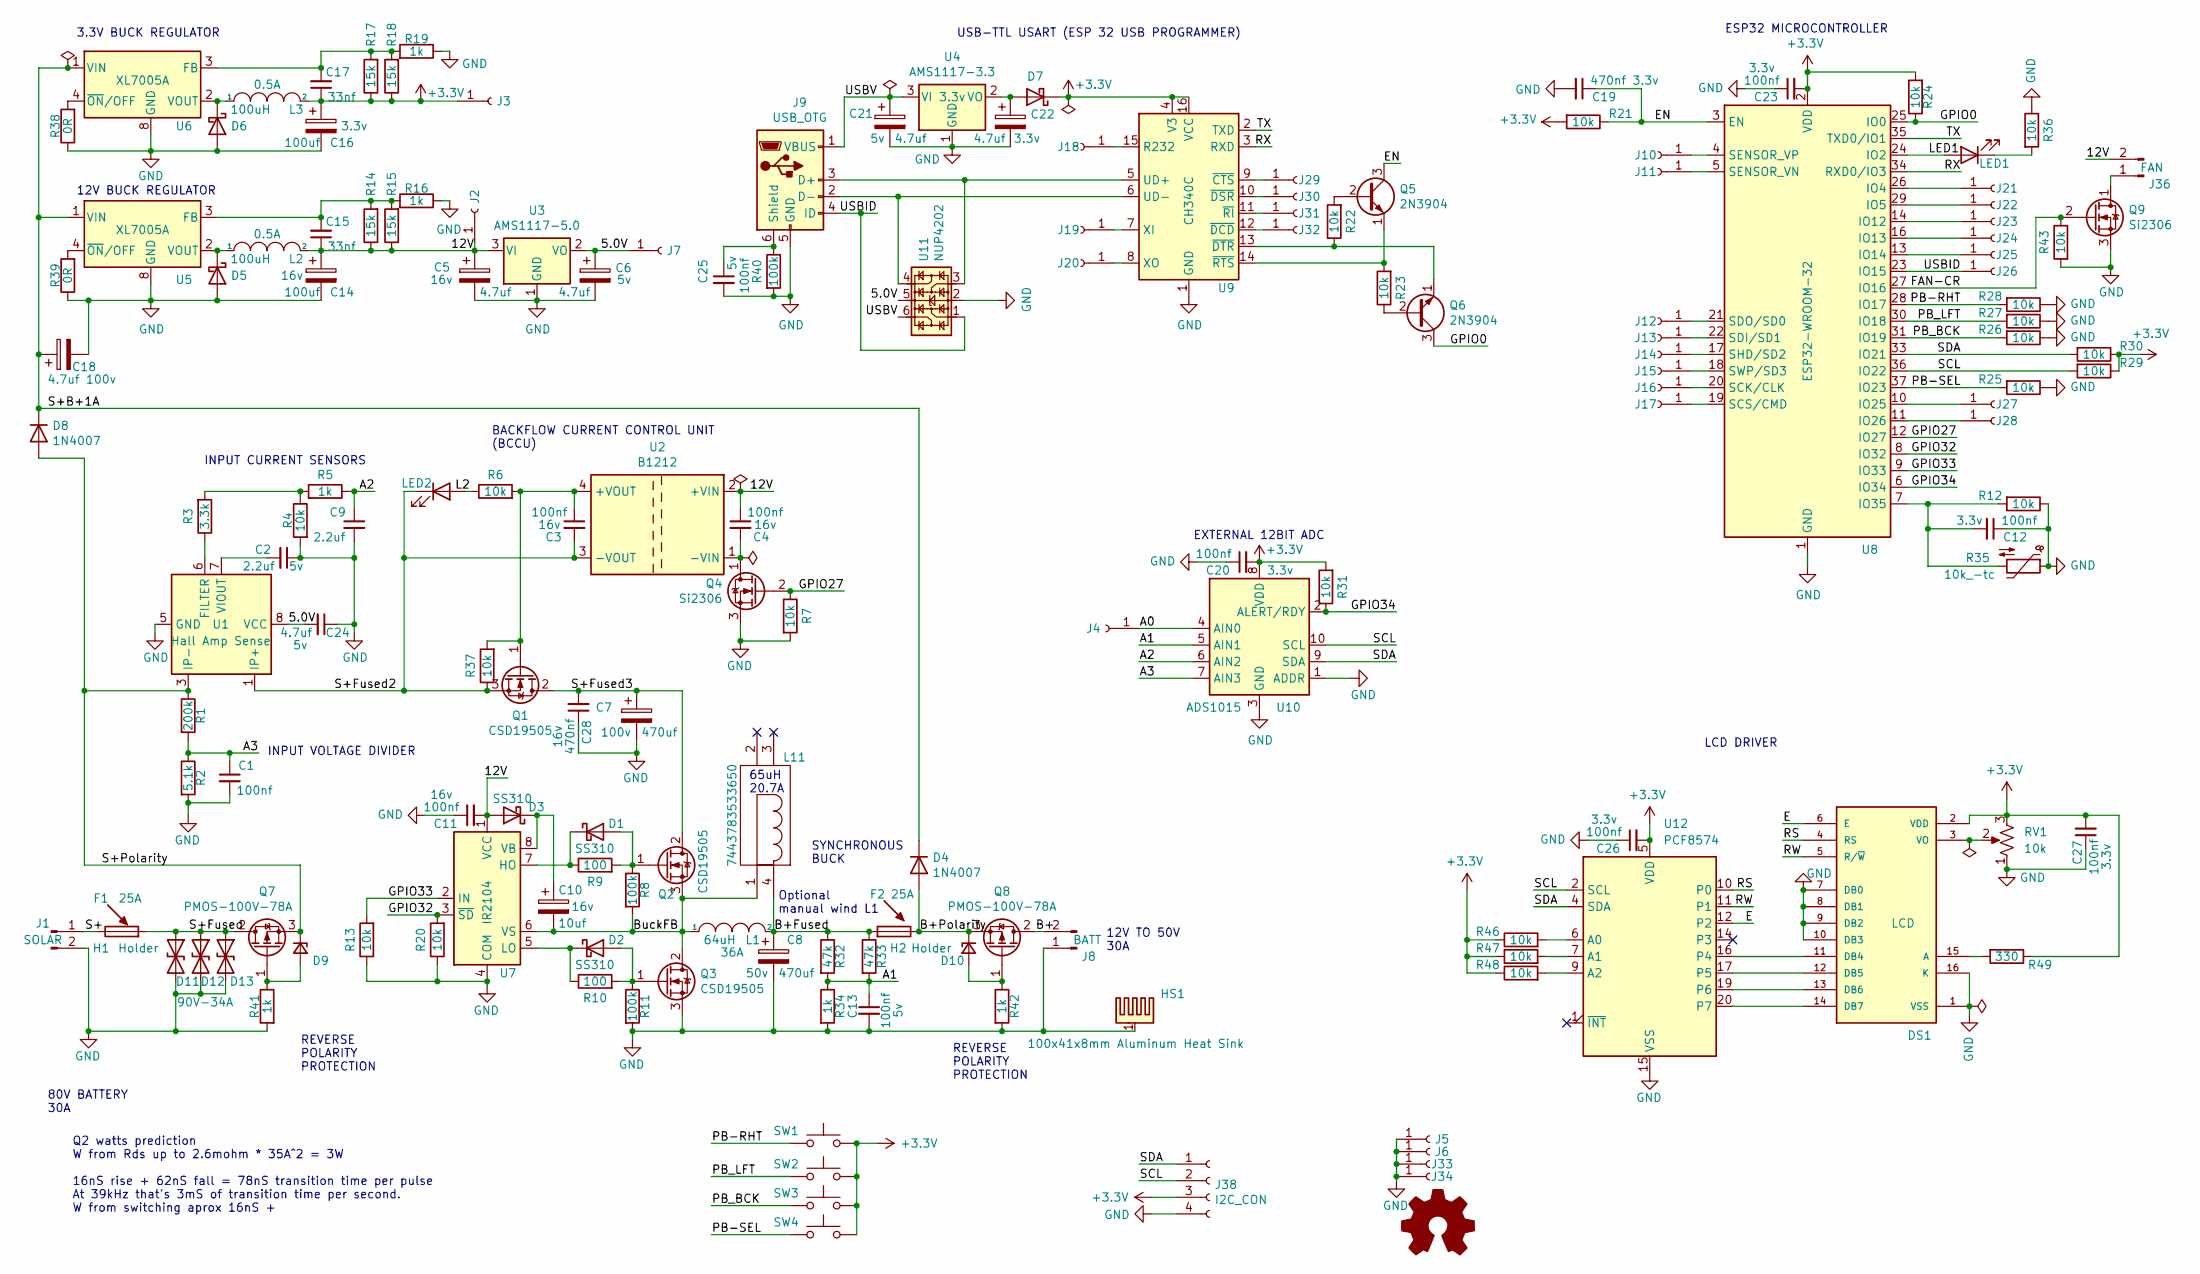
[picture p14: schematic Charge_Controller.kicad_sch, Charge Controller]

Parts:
C1, C3, C4, C11, C12, C13, C20, C23, C25, C26, C27: 100nf; C_0805_2012Metric; LCSC C28233
C2, C9: 2.2uf; C_0805_2012Metric; LCSC C49217
C5, C6, C21, C22, C24: 4.7uf; C_0805_2012Metric; LCSC C1779
C7, C8: 470uf; CP_Radial_D16.0mm_P7.50mm; LCSC C513392
C10: 10uf; C_0805_2012Metric; LCSC C15850
C14, C16: 100uf; CP_Elec_8x10; LCSC C445063
C15, C17: 33nf; C_0805_2012Metric; LCSC C53175
C18: 4.7uf; CP_Radial_D10.0mm_P5.00mm; Digikey 399-ESH107M100AH4AA-ND
C19, C28: 470nf; C_0805_2012Metric; LCSC C13967
D1, D2, D3, D5, D6, D7: SS310; D_SMA; LCSC C15874
D4, D8: 1N4007; D_SMA; LCSC C727081
D9, D10: D_Zener_Small; D_MiniMELF; LCSC C8062
D11, D12, D13: 90V-34A; D_SMC-RM10_Universal_Handsoldering; LCSC C2912801
DS1: LCD; LCD_LCM-S01602DTR_A; Digikey 3387-ACM1602K-NLW-BBW-ND
F1, F2: 25A; ESD-Logo_6.6x6mm_SilkScreen; LCSC C116701
H1, H2: Holder; Fuse_Blade_C2935871; LCSC C2935871
HS1: 100x41x8mm Aluminum Heat Sink; MountingHole_2.5mm_Pad_Via; Digikey NA
J1: SOLAR; TerminalBlock_MetzConnect_Type703_RT10N02HGLU_1x02_P9.52mm_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; LCSC C92145
J2, J3, J4, J5, J6, J7, J10, J11, J12, J13, J14, J15, J16, J17, J18, J19, J20, J21, J22, J23, J24, J25, J26, J27, J28, J29, J30, J31, J32: Conn_01x01_Female; TestPoint_Loop_D3.50mm_Drill0.9mm_Beaded; LCSC NA
J8: BATT; TerminalBlock_MetzConnect_Type703_RT10N02HGLU_1x02_P9.52mm_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; LCSC C92145
J9: USB_OTG; USB_Micro-AB_Molex_47590-0001; LCSC C136001
J33, J34: Conn_01x01_Female; MountingHole_2.5mm_Pad_Via; LCSC NA
J36: FAN; TerminalBlock_MetzConnect_Type703_RT10N02HGLU_1x02_P9.52mm_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; LCSC C92145
J38: I2C_CON; PinHeader_1x04_P2.54mm_Vertical; LCSC NA
L1: 64uH; L_Axial_L30.0mm_D8.0mm_P35.56mm_Horizontal_Fastron_77A; LCSC NA
L2, L3: 100uH; L_Taiyo-Yuden_NR-60xx_HandSoldering; LCSC C88132
L11: 7443783533650; Digikey 732-13654-ND
LED1, LED2: LED; LED_0805_2012Metric; LCSC C84256
LOGO1: Logo_Open_Hardware_Small; OSHW-Symbol_6.7x6mm_SilkScreen; LCSC NA
Q1, Q2, Q3: CSD19505; TO-263-2; LCSC C485534
Q4, Q9: Si2306; SOT-23; LCSC C347489
Q5, Q6: 2N3904; SOT-23; LCSC C18536
Q7, Q8: PMOS-100V-78A; TO-252-2; LCSC C216784
R1: 200k; R_0805_2012Metric; LCSC C17539
R2: 5.1k; R_0805_2012Metric; LCSC C27834
R3: 3.3k; R_0805_2012Metric; LCSC C26010
R4, R6, R7, R12, R13, R20, R21, R22, R23, R24, R25, R26, R27, R28, R29, R30, R31, R36, R37, R43, R46, R47, R48: 10k; R_0805_2012Metric; LCSC C17724
R5, R16, R19, R34, R41, R42: 1k; R_0805_2012Metric; LCSC C17513
R8, R11, R40: 100k; R_0805_2012Metric; LCSC C149504
R9, R10: 100; R_0805_2012Metric; LCSC C17408
R14, R15, R17, R18: 15k; R_0805_2012Metric; LCSC C17475
R32, R33: 47k; R_0805_2012Metric; LCSC C17713
R35: 10k_-tc; PinHeader_1x02_P2.54mm_Vertical; Digikey BC2380-ND
R38, R39: 0R; R_0603_1608Metric; LCSC C21189
R49: 330; R_0805_2012Metric; LCSC C17630
RV1: 10k; Potentiometer_Bourns_3314G_Vertical; LCSC C780220
SW1: RIGHT; SW_SPST_EVQQ2; LCSC C318884
SW2: LEFT; SW_SPST_EVQQ2; LCSC C318884
SW3: BACK; SW_SPST_EVQQ2; LCSC C318884
SW4: SELECT; SW_SPST_EVQQ2; LCSC C318884
U1: Hall Amp Sense; SOIC-8_3.9x4.9mm_P1.27mm; LCSC C2930869
U2: B1212; Converter_DCDC_muRata_CRE1xxxxxxSC_THT; LCSC C5127060
U3: AMS1117-5.0; SOT-223-3_TabPin2; LCSC C6187
U4: AMS1117-3.3; SOT-223-3_TabPin2; LCSC C6186
U5, U6: XL7005A; SOIC-8_3.9x4.9mm_P1.27mm; LCSC C50848
U7: IR2104; SOIC-8_3.9x4.9mm_P1.27mm; LCSC C2960
U8: ESP32-WROOM-32; LCSC C701343
U9: CH340C; STC_SOP-16_3.9x9.9mm_P1.27mm; LCSC C84681
U10: ADS1015; TSSOP-10_3x3mm_P0.5mm; LCSC C193969
U11: NUP4202; SOT-363_SC-70-6; LCSC C89319
U12: PCF8574; SSOP-20_5.3x7.2mm_P0.65mm; LCSC C57790

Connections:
+3.3VA: C16.1, C17.1, C20.2, C23.2, C26.2, C27.2, D7.1 (K), DS1.2 (VDD), J3.1, J38.3, L3.2, R17.1, R18.1, R21.2, R24.2, R29.1, R30.1, R31.2, R46.1, R47.1, R48.1, R49.1, RV1.3, SW1.2, SW2.2, SW3.2, SW4.2, U8.2 (VDD), U9.4 (V3), U9.16 (VCC), U10.8 (VDD), U12.5 (VDD)
/5.0V: C6.1, C24.2, J7.1, U1.8 (VCC), U3.2 (VO), U11.5
/12V: C4.1, C5.1, C11.2, C14.1, C15.1, D3.2 (A), J2.1, J36.2, L2.2, R14.1, R15.1, U2.2 (+VIN), U3.3 (VI), U7.1 (VCC)
/A0: J4.1, U10.4 (AIN0)
/A1: C13.1, R32.2, R33.2, R34.1, U10.5 (AIN1)
/A2: C9.1, R5.1, U10.6 (AIN2)
/A3: C1.1, R1.2, R2.1, U10.7 (AIN3)
/B+: J8.2, Q8.2 (D)
/B+Fused: C8.1, H2.2, L1.2, L11.4, R32.1, R33.1
/B+Polarity: D4.2 (A), D10.1 (K), H2.1, Q8.3 (S)
/BuckFB: C10.2, L1.1, L11.1, Q2.3 (S), Q3.2 (D), R8.2, U7.6 (VS)
/E: DS1.6 (E), U12.12 (P2)
/EN: C19.1, Q5.3 (C), R21.1, U8.3 (EN)
/FAN-CR: Q9.2 (G), R43.1, U8.27 (IO16)
/GPIO0: Q6.3 (C), R24.1, U8.25 (IO0)
/GPIO27: Q4.2 (G), R7.1, U8.12 (IO27)
/GPIO32: R20.2, U7.3 (~SD), U8.8 (IO32)
/GPIO33: R13.2, U7.2 (IN), U8.9 (IO33)
/GPIO34: R31.1, U8.6 (IO34), U10.2 (ALERT/RDY)
/L2: LED2.2 (A), R6.1
/LED1: LED1.2 (A), U8.24 (IO2)
/PB-RHT: R28.2, SW1.1, U8.28 (IO17)
/PB-SEL: R25.2, SW4.1, U8.37 (IO23)
/PB_BCK: R26.2, SW3.1, U8.31 (IO19)
/PB_LFT: R27.2, SW2.1, U8.30 (IO18)
/RS: DS1.4 (RS), U12.10 (P0)
/RW: DS1.5 (R/~W), U12.11 (P1)
/RX: U8.34 (RXD0/IO3), U9.3 (RXD)
/S+: H1.1, J1.1
/S+B+1A: C18.1, D4.1 (K), D8.1 (K), U5.1 (VIN), U6.1 (VIN)
/S+Fused: D11.1 (A1), D12.1 (A1), D13.1 (A1), H1.2, Q7.2 (D)
/S+Fused2: C3.2, LED2.1 (K), Q1.3 (S), R37.1, U1.1 (IP+), U1.2 (IP+), U2.3 (-VOUT)
/S+Fused3: C7.1, C28.2, Q1.2 (D), Q2.2 (D)
/S+Polarity: D8.2 (A), D9.1 (K), Q7.3 (S), R1.1, U1.3 (IP-), U1.4 (IP-)
/SCL: J38.2, R29.2, U8.36 (IO22), U10.10 (SCL), U12.2 (SCL)
/SDA: J38.1, R30.2, U8.33 (IO21), U10.9 (SDA), U12.4 (SDA)
/TX: U8.35 (TXD0/IO1), U9.2 (TXD)
/USBID: J9.4 (ID), J26.1, U8.23 (IO15), U11.1
/USBV: C21.1, J9.1 (VBUS), U4.3 (VI), U11.6
GND: C1.2, C2.1, C5.2, C6.2, C7.2, C8.2, C9.2, C11.1, C12.1, C13.2, C14.2, C16.2, C18.2, C19.2, C20.1, C21.2, C22.2, C23.1, C24.1, C25.2, C26.1, C27.1, C28.1, D5.2 (A), D6.2 (A), D11.2 (A2), D12.2 (A2), D13.2 (A2), DS1.1 (VSS), DS1.7 (DB0), DS1.8 (DB1), DS1.9 (DB2), DS1.10 (DB3), DS1.16 (K), HS1.1, J1.2, J5.1, J6.1, J8.1, J9.5 (GND), J33.1, J34.1, J38.4, Q3.3 (S), Q4.3 (S), Q9.3 (S), R2.2, R4.2, R7.2, R11.2, R12.1, R13.1, R16.1, R19.1, R20.1, R25.1, R26.1, R27.1, R28.1, R34.2, R35.1, R36.1, R38.1, R39.1, R40.2, R41.2, R42.2, R43.2, RV1.1, U1.5 (GND), U3.1 (GND), U4.1 (GND), U5.5 (GND), U5.6 (GND), U5.7 (GND), U5.8 (GND), U6.5 (GND), U6.6 (GND), U6.7 (GND), U6.8 (GND), U7.4 (COM), U8.1 (GND), U8.15 (GND), U8.38 (GND), U8.39 (GND), U9.1 (GND), U10.1 (ADDR), U10.3 (GND), U11.2, U12.15 (VSS)
unnamed: C2.2, U1.7 (VIOUT)
unnamed: C3.1, Q1.1 (G), R6.2, R37.2, U2.4 (+VOUT)
unnamed: C4.2, Q4.1 (D), U2.1 (-VIN)
unnamed: C10.1, D3.1 (K), U7.8 (VB)
unnamed: C12.2, R12.2, R35.2, U8.7 (IO35)
unnamed: C15.2, R14.2, R15.2, R16.2, U5.3 (FB)
unnamed: C17.2, R17.2, R18.2, R19.2, U6.3 (FB)
unnamed: C22.1, D7.2 (A), U4.2 (VO)
unnamed: C25.1, J9.6 (Shield), R40.1
unnamed: D1.1 (K), R9.1, U7.7 (HO)
unnamed: D1.2 (A), Q2.1 (G), R8.1, R9.2
unnamed: D2.1 (K), R10.1, U7.5 (LO)
unnamed: D2.2 (A), Q3.1 (G), R10.2, R11.1
unnamed: D5.1 (K), L2.1, U5.2 (VOUT)
unnamed: D6.1 (K), L3.1, U6.2 (VOUT)
unnamed: D9.2 (A), Q7.1 (G), R41.1
unnamed: D10.2 (A), Q8.1 (G), R42.1
unnamed: DS1.3 (VO), RV1.2
unnamed: DS1.11 (DB4), U12.16 (P4)
unnamed: DS1.12 (DB5), U12.17 (P5)
unnamed: DS1.13 (DB6), U12.19 (P6)
unnamed: DS1.14 (DB7), U12.20 (P7)
unnamed: DS1.15 (A), R49.2
unnamed: J9.2 (D-), U9.6 (UD-), U11.4
unnamed: J9.3 (D+), U9.5 (UD+), U11.3
unnamed: J10.1, U8.4 (SENSOR_VP)
unnamed: J11.1, U8.5 (SENSOR_VN)
unnamed: J12.1, U8.21 (SDO/SD0)
unnamed: J13.1, U8.22 (SDI/SD1)
unnamed: J14.1, U8.17 (SHD/SD2)
unnamed: J15.1, U8.18 (SWP/SD3)
unnamed: J16.1, U8.20 (SCK/CLK)
unnamed: J17.1, U8.19 (SCS/CMD)
unnamed: J18.1, U9.15 (R232)
unnamed: J19.1, U9.7 (XI)
unnamed: J20.1, U9.8 (XO)
unnamed: J21.1, U8.26 (IO4)
unnamed: J22.1, U8.29 (IO5)
unnamed: J23.1, U8.14 (IO12)
unnamed: J24.1, U8.16 (IO13)
unnamed: J25.1, U8.13 (IO14)
unnamed: J27.1, U8.10 (IO25)
unnamed: J28.1, U8.11 (IO26)
unnamed: J29.1, U9.9 (~CTS)
unnamed: J30.1, U9.10 (~DSR)
unnamed: J31.1, U9.11 (~RI)
unnamed: J32.1, U9.12 (~DCD)
unnamed: LED1.1 (K), R36.2
unnamed: Q5.1 (E), R23.2, U9.14 (~RTS)
unnamed: Q5.2 (B), R22.2
unnamed: Q6.1 (E), R22.1, U9.13 (~DTR)
unnamed: Q6.2 (B), R23.1
unnamed: J36.1, Q9.1 (D)
unnamed: R3.1, U1.6 (FILTER)
unnamed: R3.2, R4.1, R5.2
unnamed: R38.2, U6.4 (~ON/OFF)
unnamed: R39.2, U5.4 (~ON/OFF)
unnamed: R46.2, U12.6 (A0)
unnamed: R47.2, U12.7 (A1)
unnamed: R48.2, U12.9 (A2)

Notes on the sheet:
SYNCHRONOUS BUCK
3.3V BUCK REGULATOR
USB-TTL USART (ESP 32 USB PROGRAMMER)
Optional manual wind L1
BACKFLOW CURRENT CONTROL UNIT (BCCU)
65uH 20.7A
12V BUCK REGULATOR
80V BATTERY 30A
INPUT CURRENT SENSORS
REVERSE POLARITY PROTECTION
Q2 watts prediction W from Rds up to 2.6mohm * 35A^2 = 3W 16nS rise + 62nS fall = 78nS transition time per pulse At 39kHz that's 3mS of transition time per second. W from switching aprox 16nS +
LCD DRIVER
INPUT VOLTAGE DIVIDER
12V TO 50V 30A
ESP32 MICROCONTROLLER
EXTERNAL 12BIT ADC

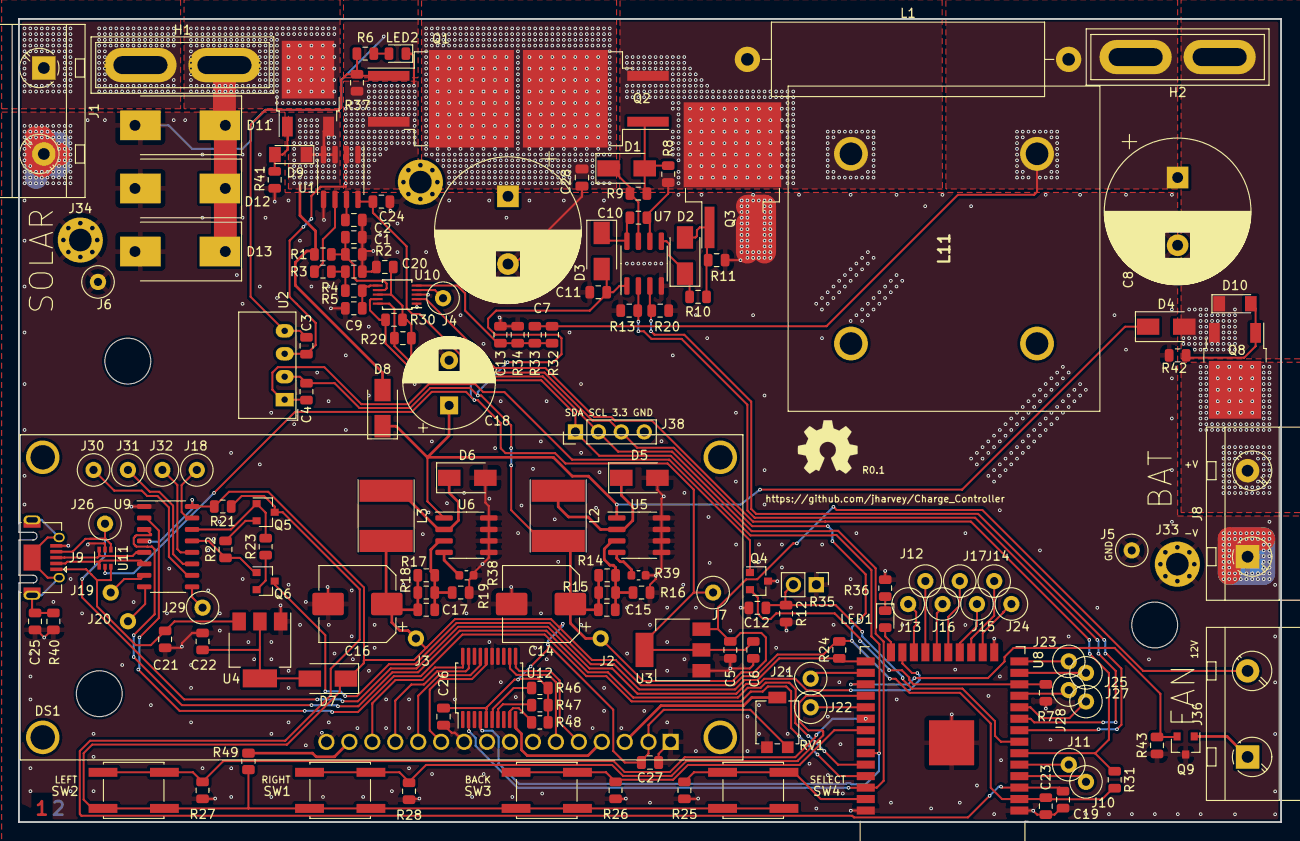
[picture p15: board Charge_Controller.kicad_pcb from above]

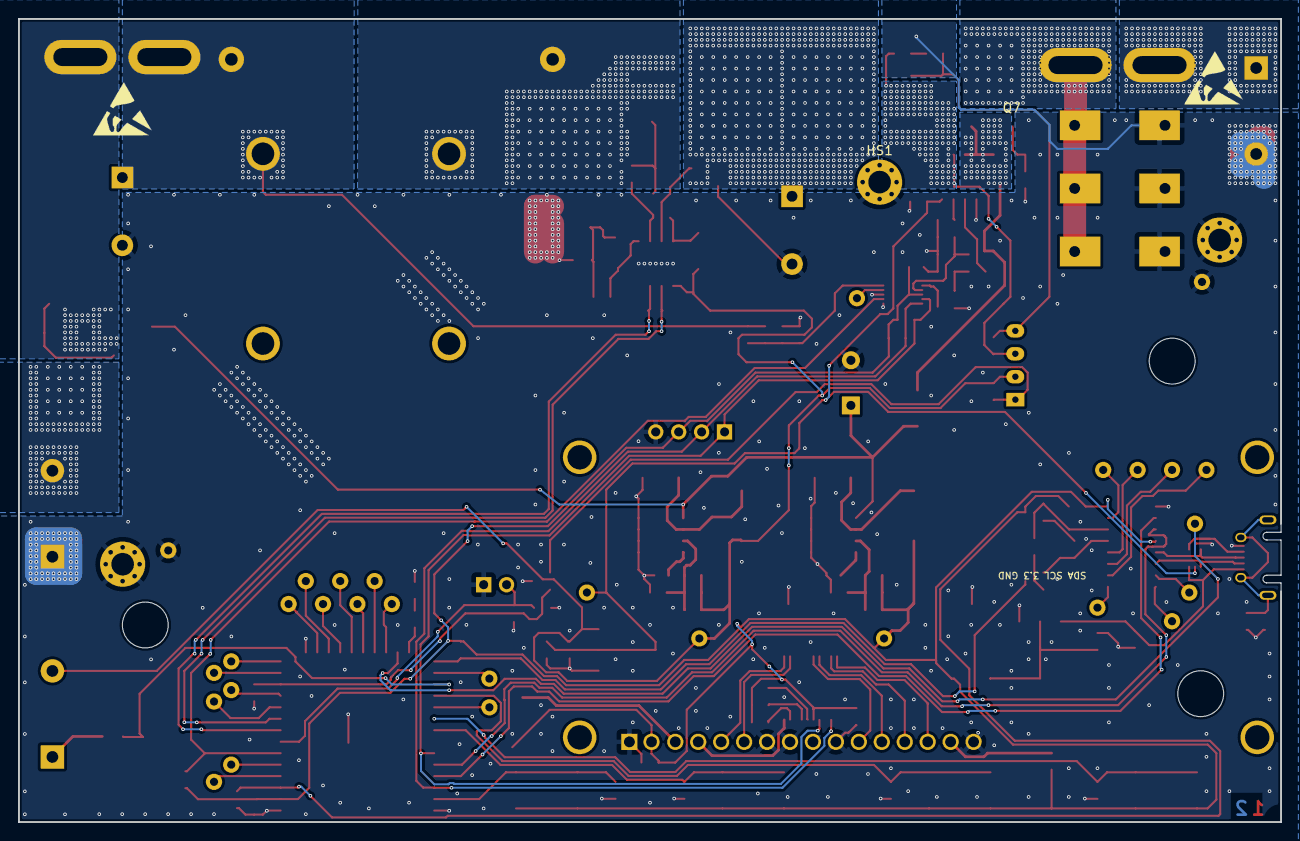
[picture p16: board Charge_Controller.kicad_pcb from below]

Board: 2 copper layers, 139.7 x 88.9 mm, 163 parts (3 on the bottom side), 100 nets.

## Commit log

2022-08-14 Initial Schematic capture DRAFT
    [Charge_Controller.kicad_pcb, Charge_Controller.sch]
2022-08-14 Draft BOM, ADDED surge and reverse polarity protection U11, Q7, Q8
    [Charge_Controller.sch]
2022-08-15 Aligned footprints with JLPCB rotations and offsets, deleted some JLCPCB automation files.
    [Charge_Controller.kicad_pcb, Charge_Controller.sch]
2022-08-15 Added FAN controller circuit
    [Charge_Controller.kicad_pcb, Charge_Controller.sch]
2022-08-16 Added push buttons, LCD connector, and fan MOSFET to schematic.
    [Charge_Controller.sch]
2022-08-17 Started layout of PCB, first grouping of components.
    [Charge_Controller.kicad_pcb, Charge_Controller.sch]
2022-08-20 Initial draft layout, no traces yet, but parts are mostly arranged.
    [Charge_Controller.kicad_pcb, Charge_Controller.sch]
2022-08-20 More PCB initial setup, 2oz copper, widths, via's etc.
    [Charge_Controller.kicad_pcb, Charge_Controller.sch]
2022-08-20 Converted to KCAD 6, more draft layout.
    [Charge_Controller.kicad_pcb]
2022-08-21 Another incremental layout draft.
    [Charge_Controller.kicad_pcb]
2022-08-22 Draft, no more courtyard problems, all traces connected
    [Charge_Controller.kicad_pcb]
2022-08-22 Not sure why these were not part of the repo, adding them now. Oops.
    [Charge_Controller.kicad_sch]
2022-08-23 Draft adding I2C to LCD driver.
    [Charge_Controller.kicad_sch]
2022-08-26 R0.1 almost done draft.
    [Charge_Controller.kicad_pcb, Charge_Controller.kicad_sch]
2022-08-26 Added a bit of silk screen.
    [Charge_Controller.kicad_pcb]
2022-08-27 changed some wrl's to step files, Made 3D case for PCB via OnShape
    [Charge_Controller.kicad_pcb]
2022-08-27 Attempting to export a BOM, save before doing something potentially risky.
    [Charge_Controller.kicad_pcb, Charge_Controller.kicad_sch]
2022-08-27 Potentially going to release this as the first spin.
    [Buttons.step, Charge_Controller.kicad_pcb, Charge_Controller.kicad_sch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]
2022-08-28 Added a Digikey number for the toroid.
    [Charge_Controller.kicad_sch, Charge_Controller_BOM.csv, Charge_Controller_full - Charge_Controller_BOM.csv]
2022-09-05 Moved C7 to other side of current sensor, changed C7 and C8 from Axial to Radial, moved U3 slightly. https://github.com/jharvey/Charge_Controller/issues/2
    [Charge_Controller.kicad_pcb, Charge_Controller.kicad_sch, Charge_Controller_JLC-BOM.csv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]
2022-09-05 Added D11, D12 and D13 for input surge protection. https://github.com/jharvey/Charge_Controller/issues/3
    [Charge_Controller.kicad_pcb, Charge_Controller.kicad_sch, Charge_Controller_JLC-BOM.csv]
2022-09-05 Changed the hall sensor and added some notes.
    [Charge_Controller.kicad_pcb, Charge_Controller.kicad_sch, Charge_Controller_JLC-BOM.csv]
2022-09-07 Initial simulation for Q1 and Q2 MOSFET heat
2022-09-08 Small progress on heat sim. This model shows KA of current from the MOSFET's. Looks like I'll have to use the file based voltage control instead of the generic pulse power supplies. \https://github.c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
2022-09-09 Created PWL bases simulation, and made heat predictions.
    [Charge_Controller_Heat_pulses.xlsx]
2022-09-11 Heat load simulation at 12A steady state. Added several simulations, including CSD17510Q5A.spice.mod imported from the PSPICE for TI model.
2022-09-11 Added more pictures of specific volts, amps, etc. Pictures showing key simulation items.
2022-09-20 Draft layout, still needs a bunch, but everything is connected.
    [Charge_Controller.kicad_pcb, Charge_Controller.kicad_sch]
2022-09-20 Peppered it with via's, silk screen is probably good a this point. Almost ready for a review.
    [Charge_Controller.kicad_pcb]
2022-09-22 R0.1 ready for review
    [Buttons.step, Charge_Controller.kicad_pcb, Charge_Controller.kicad_sch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]
2022-09-23 Added some documentation for thermal via predictions and buck regulator design.
2022-09-24 Updated Q2 and Q3 watts prediction note on schematic. It now notes the spice simulation prediction watts.
    [Charge_Controller.kicad_sch]
2022-09-24 Updated mechanical drawing of the final enclosure.
